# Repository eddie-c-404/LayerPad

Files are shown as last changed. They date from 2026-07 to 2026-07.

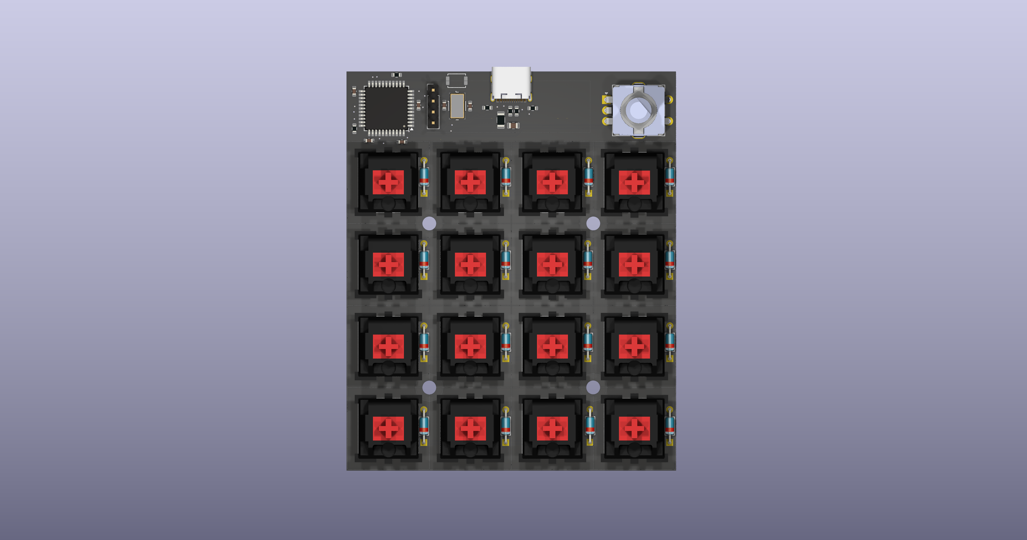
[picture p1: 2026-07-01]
Images/Render_Top_ZO.png

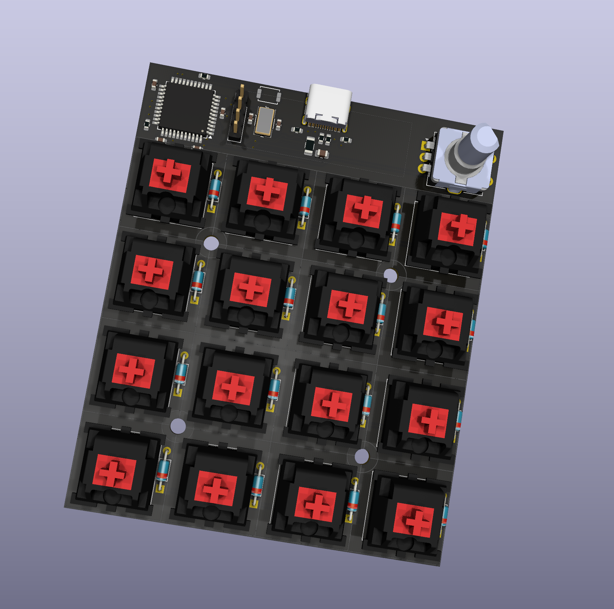
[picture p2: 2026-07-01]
Images/Render_Top2.png

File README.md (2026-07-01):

# LayerPad
Highly customizable macropad for creators.



## Why?
This project was meant to assist me in being more efficient in my day-to-day activities through the use of the shortcut keys and macros which I frequently use. Through the use of programmable keys, several layers, the rotary encoder and an OLED screen, the macropad is able to be programmed for various uses including Visual Studio, Fusion 360, KiCad and Blender. The aim is to have a small but highly customizable productivity aid which can assist anyone in organizing their workspace.
## Features
- 16 programmable mechanical keys

- Rotary encoder with push button

- OLED display

- USB-C connectivity

- Powered by the ATmega32U4

- Compatible with QMK firmware

## 🚧 Build Status 
| Component | Status | 
|---|---|
| PCB Design | 🚧 In Progress | 
| Schematic | 🚧 In Progress | 
| Case Design | 🚧 In Progress | 
| Firmware | ⏳ Planned | 
| Prototype | ⏳ Planned |

## Future Improvements

- RGB underglow

- Multiple rotary encoders

- Wireless (Bluetooth) version

- Aluminum enclosure

- VIA/Vial support

- Low-profile switch version

- Additional OLED animations

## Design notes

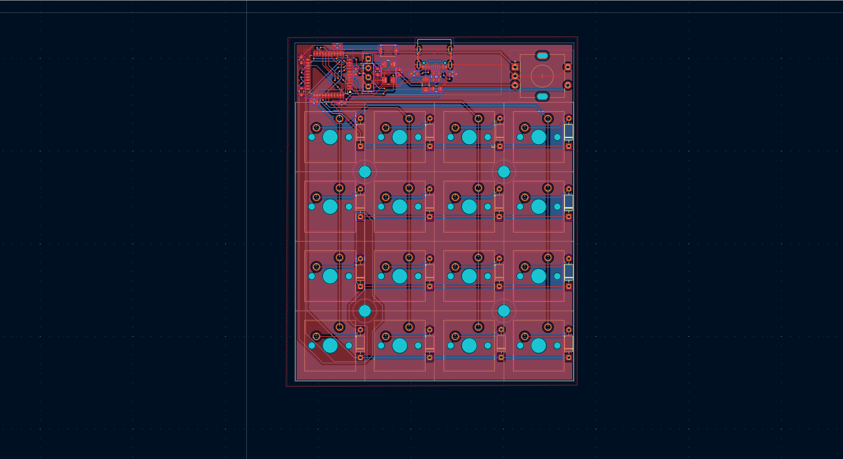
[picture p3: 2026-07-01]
Images/PCB_Top.png

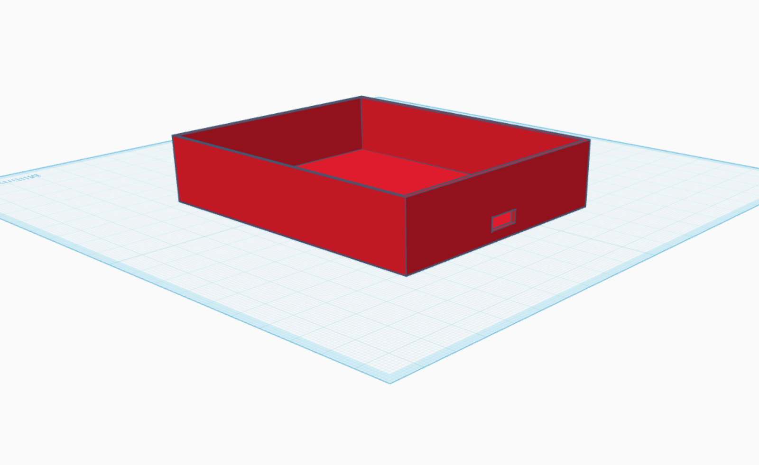
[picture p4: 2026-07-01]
Images/Case_Side.png

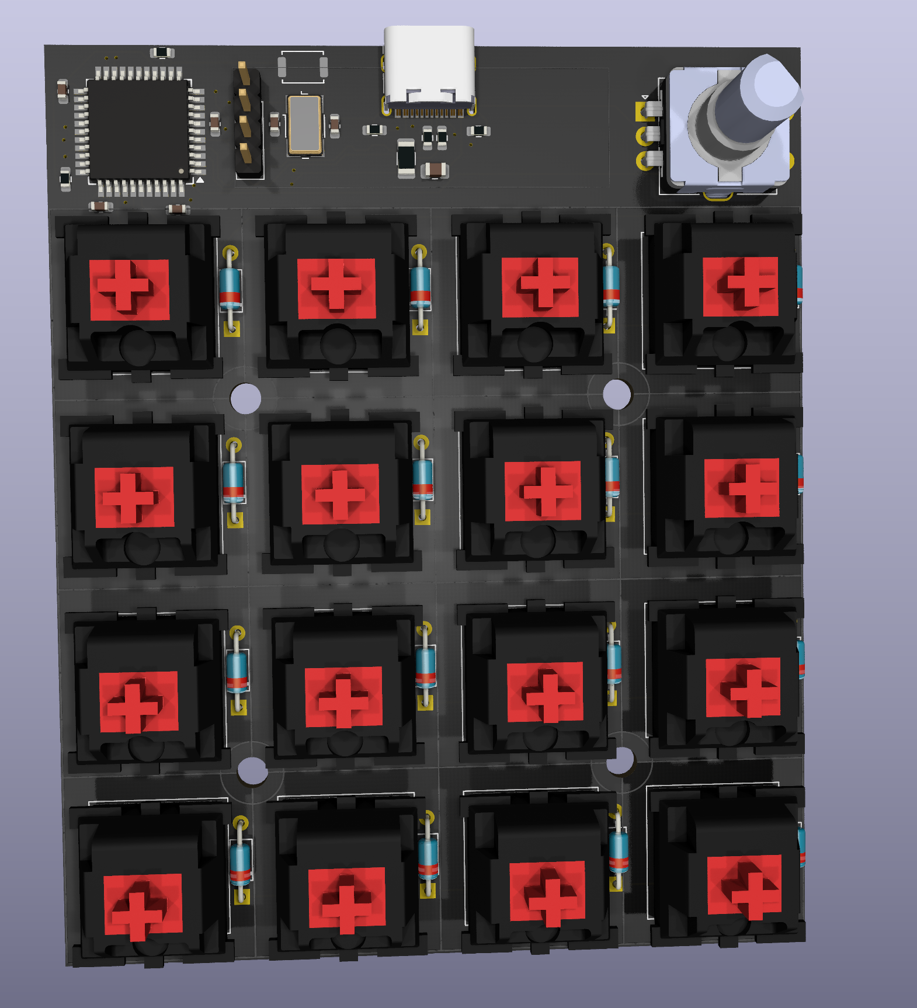
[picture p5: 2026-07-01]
Images/Render_Top.png

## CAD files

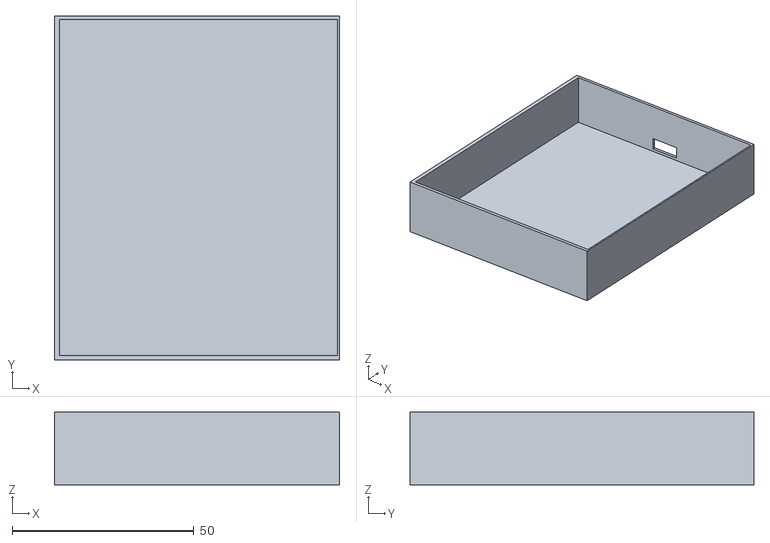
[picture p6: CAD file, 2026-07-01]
3D Files/simpleCase.stl
78.6 x 94.8 x 20.0

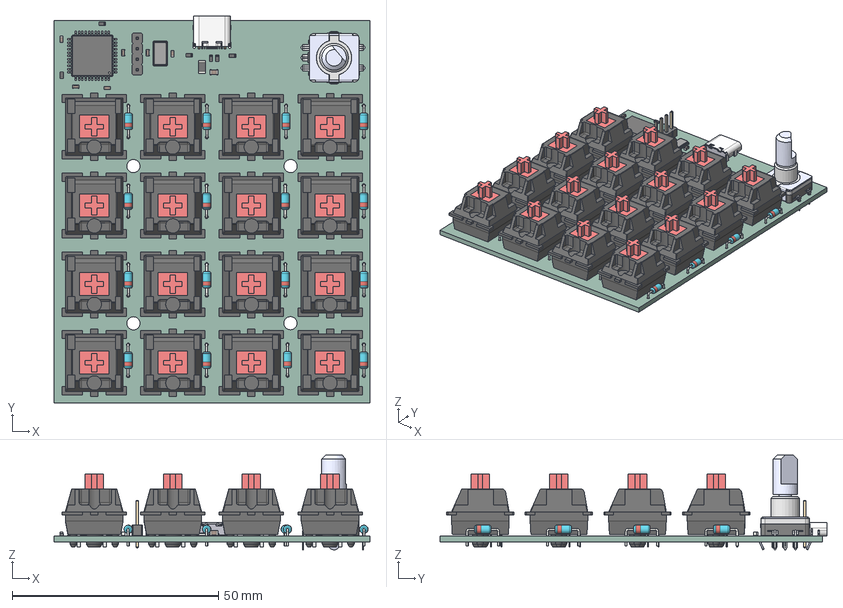
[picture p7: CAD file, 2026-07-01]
KiCad Files/LayerPad-v1.step
76.6 x 93.8 x 23.0 mm
D_DO-35_SOD27_P7.62mm_Horizontal x 16
R_0603_1608Metric x 6
Crystal_SMD_0603-4Pin_6.0x3.5mm
C_0603_1608Metric x 6
PinHeader_1x04_P2.54mm_Vertical
C_0805_2012Metric
tongue
shield
contact_001
contact_002
contact_003
contact_004
contact_court_001
contact_court_002
contact_court_003
contact_court_004
contact_005
contact_006
contact_007
contact_008
contact_court_005
contact_court_006
contact_court_007
contact_court_008
pin_001
pin_002
pin_003
pin_004
pin_005
pin_006
pin_007
pin_008
pin_009
pin_010
pin_011
pin_012
pin_013
pin_014
pin_015
pin_016
Fuse_1206_3216Metric
EC11-Base
EC11-Shaft-F
EC11-Housing-THT
TQFP-44_10x10mm_P0.8mm
LayerPad-v1_PCB

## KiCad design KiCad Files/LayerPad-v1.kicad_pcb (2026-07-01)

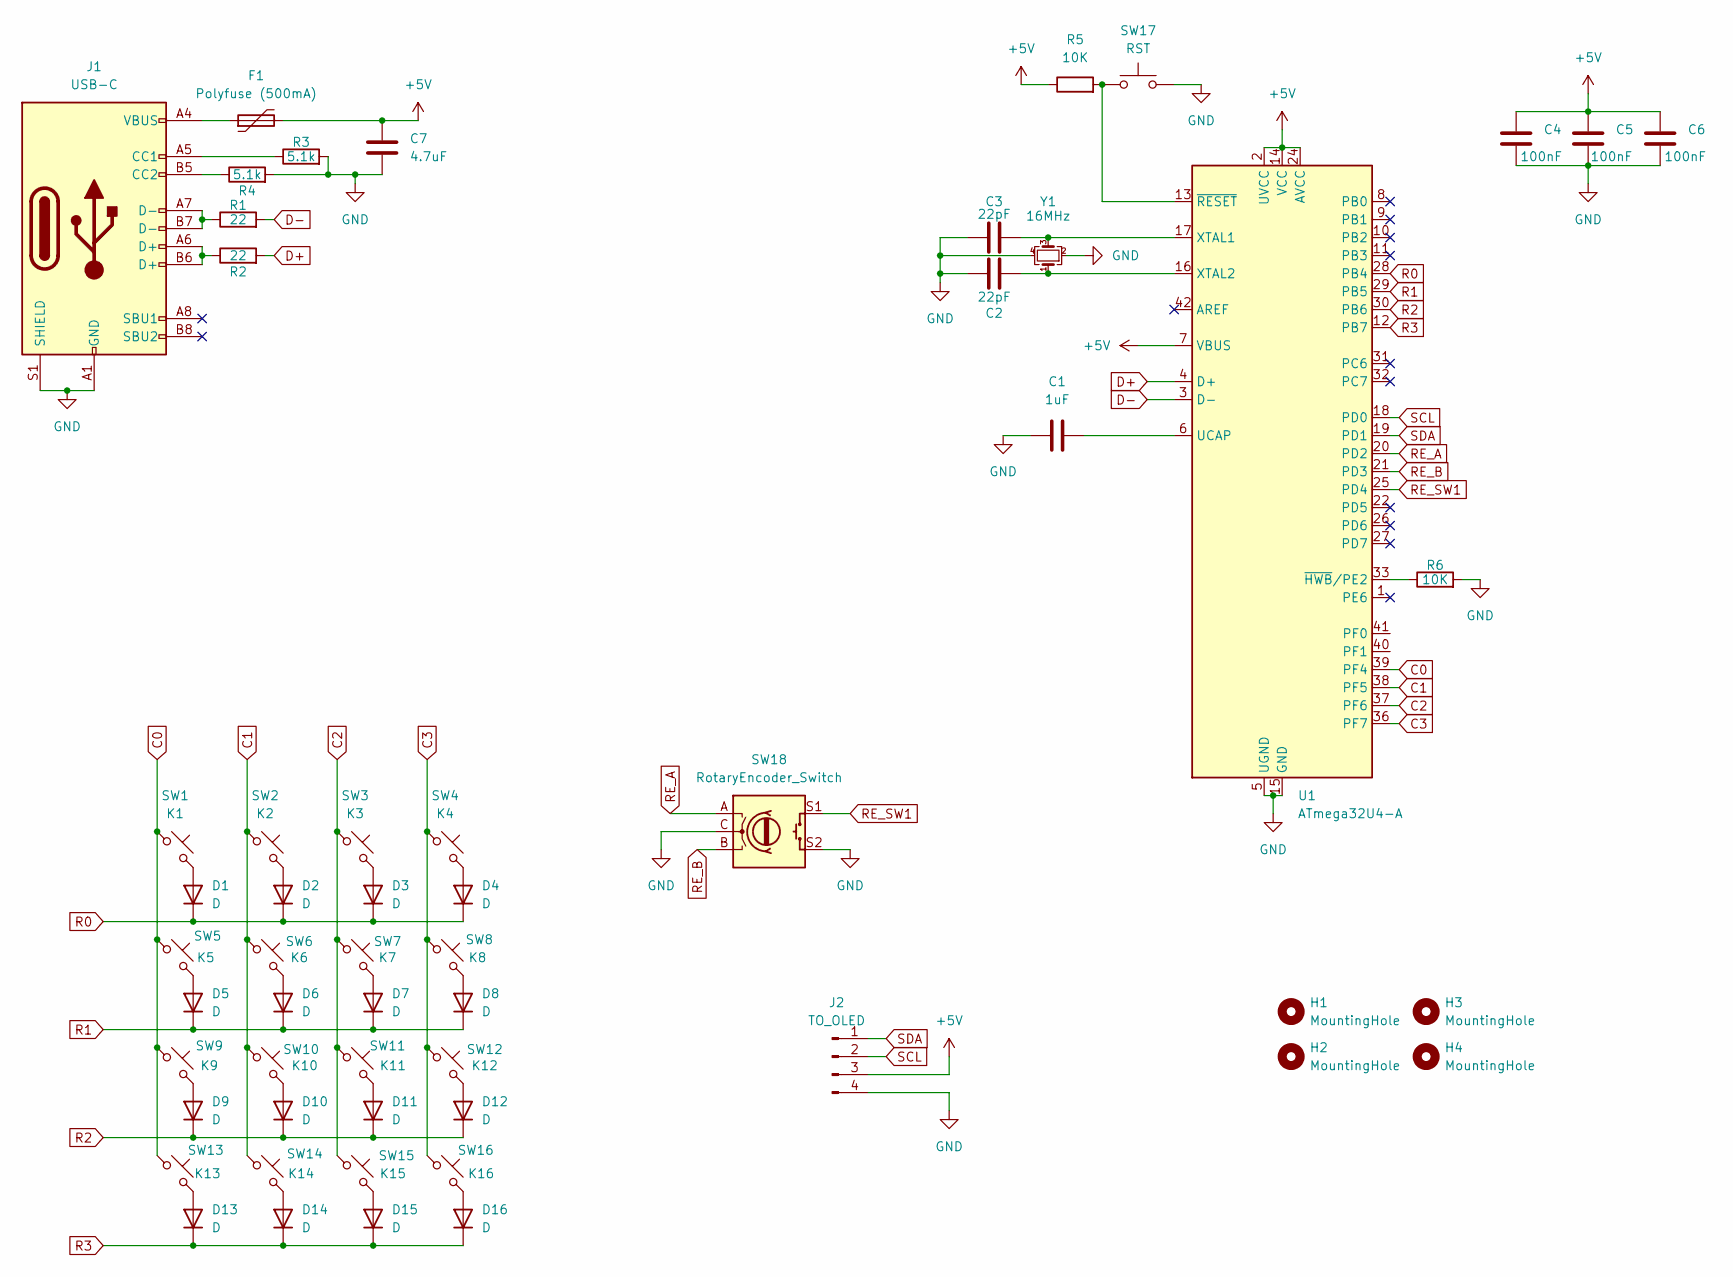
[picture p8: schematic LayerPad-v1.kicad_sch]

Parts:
C1: 1uF; C_0603_1608Metric
C2, C3: 22pF; C_0603_1608Metric
C4, C5, C6: 100nF; C_0603_1608Metric
C7: 4.7uF; C_0805_2012Metric
D1, D2, D3, D4, D5, D6, D7, D8, D9, D10, D11, D12, D13, D14, D15, D16: D; D_DO-35_SOD27_P7.62mm_Horizontal
F1: Polyfuse (500mA); Fuse_1206_3216Metric
H1, H2, H3, H4: MountingHole; MountingHole_3.2mm_M3
J1: USB-C; USB_C_Receptacle_G-Switch_GT-USB-7010ASV
J2: TO_OLED; PinHeader_1x04_P2.54mm_Vertical
R1, R2: 22; R_0603_1608Metric
R3, R4: 5.1k; R_0603_1608Metric
R5, R6: 10K; R_0603_1608Metric
SW1: K1; SW_Cherry_MX_1.00u_PCB
SW2: K2; SW_Cherry_MX_1.00u_PCB
SW3: K3; SW_Cherry_MX_1.00u_PCB
SW4: K4; SW_Cherry_MX_1.00u_PCB
SW5: K5; SW_Cherry_MX_1.00u_PCB
SW6: K6; SW_Cherry_MX_1.00u_PCB
SW7: K7; SW_Cherry_MX_1.00u_PCB
SW8: K8; SW_Cherry_MX_1.00u_PCB
SW9: K9; SW_Cherry_MX_1.00u_PCB
SW10: K10; SW_Cherry_MX_1.00u_PCB
SW11: K11; SW_Cherry_MX_1.00u_PCB
SW12: K12; SW_Cherry_MX_1.00u_PCB
SW13: K13; SW_Cherry_MX_1.00u_PCB
SW14: K14; SW_Cherry_MX_1.00u_PCB
SW15: K15; SW_Cherry_MX_1.00u_PCB
SW16: K16; SW_Cherry_MX_1.00u_PCB
SW17: RST; SW_Push_SPST_NO_Alps_SKRK
SW18: RotaryEncoder_Switch; RotaryEncoder_EC11
U1: ATmega32U4-A; TQFP-44_10x10mm_P0.8mm
Y1: 16MHz; Crystal_SMD_0603-4Pin_6.0x3.5mm

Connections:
+5V: C4.1, C5.1, C6.1, C7.1, F1.2, J2.3, R5.1, U1.2 (UVCC), U1.7 (VBUS), U1.14 (VCC), U1.24 (AVCC), U1.34 (VCC), U1.44 (AVCC)
C0: SW1.1, SW5.1, SW9.1, SW13.1, U1.39 (PF4)
C1: SW2.1, SW6.1, SW10.1, SW14.1, U1.38 (PF5)
C2: SW3.1, SW7.1, SW11.1, SW15.1, U1.37 (PF6)
C3: SW4.1, SW8.1, SW12.1, SW16.1, U1.36 (PF7)
D+: R2.2, U1.4 (D+)
D-: R1.2, U1.3 (D-)
GND: C1.1, C2.1, C3.1, C4.2, C5.2, C6.2, C7.2, J1.A1 (GND), J1.A12 (GND), J1.B1 (GND), J1.B12 (GND), J1.S1 (SHIELD), J2.4, R3.2, R4.2, R6.2, SW17.2, SW18.C, SW18.S2, U1.5 (UGND), U1.15 (GND), U1.23 (GND), U1.35 (GND), U1.43 (GND), Y1.2, Y1.4
unnamed: D1.2 (A), SW1.2
unnamed: D2.2 (A), SW2.2
unnamed: D3.2 (A), SW3.2
unnamed: D4.2 (A), SW4.2
unnamed: D5.2 (A), SW5.2
unnamed: D6.2 (A), SW6.2
unnamed: D7.2 (A), SW7.2
unnamed: D8.2 (A), SW8.2
unnamed: D9.2 (A), SW9.2
unnamed: D10.2 (A), SW10.2
unnamed: D11.2 (A), SW11.2
unnamed: D12.2 (A), SW12.2
unnamed: D13.2 (A), SW13.2
unnamed: D14.2 (A), SW14.2
unnamed: D15.2 (A), SW15.2
unnamed: D16.2 (A), SW16.2
unnamed: F1.1, J1.A4 (VBUS), J1.A9 (VBUS), J1.B4 (VBUS), J1.B9 (VBUS)
unnamed: J1.A5 (CC1), R3.1
unnamed: J1.B5 (CC2), R4.1
unnamed: J1.A6 (D+), J1.B6 (D+), R2.1
unnamed: J1.A7 (D-), J1.B7 (D-), R1.1
unnamed: C1.2, U1.6 (UCAP)
unnamed: C3.2, U1.17 (XTAL1), Y1.3
unnamed: C2.2, U1.16 (XTAL2), Y1.1
unnamed: R6.1, U1.33 (~HWB/PE2)
unnamed: R5.2, SW17.1, U1.13 (~RESET)
R0: D1.1 (K), D2.1 (K), D3.1 (K), D4.1 (K), U1.28 (PB4)
R1: D5.1 (K), D6.1 (K), D7.1 (K), D8.1 (K), U1.29 (PB5)
R2: D9.1 (K), D10.1 (K), D11.1 (K), D12.1 (K), U1.30 (PB6)
R3: D13.1 (K), D14.1 (K), D15.1 (K), D16.1 (K), U1.12 (PB7)
RE_A: SW18.A, U1.20 (PD2)
RE_B: SW18.B, U1.21 (PD3)
RE_SW1: SW18.S1, U1.25 (PD4)
SCL: J2.2, U1.18 (PD0)
SDA: J2.1, U1.19 (PD1)

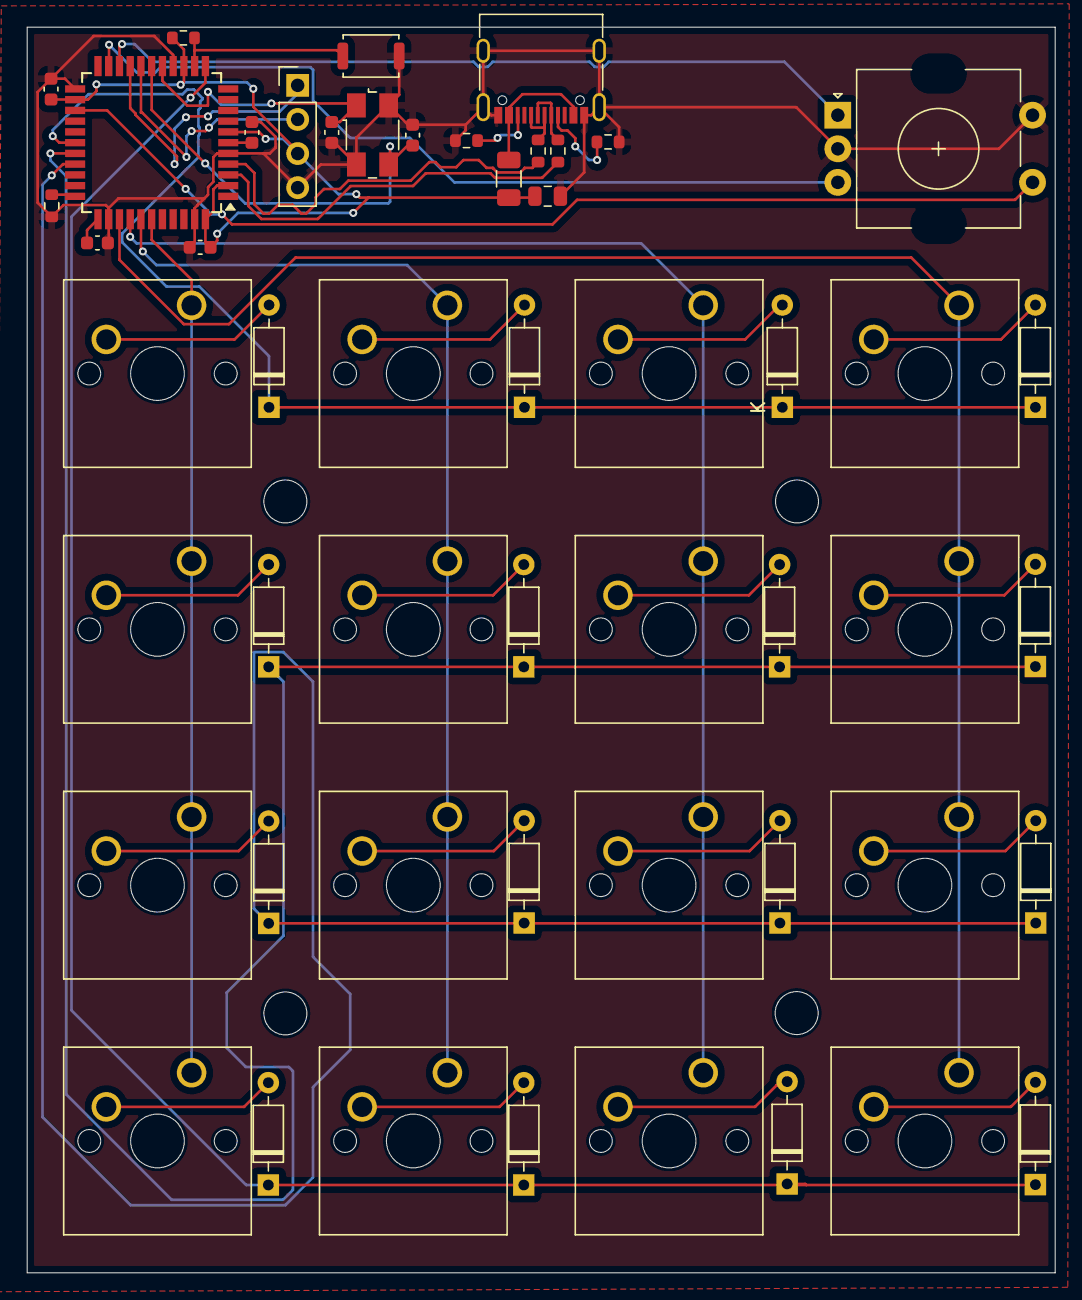
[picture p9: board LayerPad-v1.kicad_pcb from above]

Board: 2 copper layers, 76.6 x 92.8 mm, 56 parts (0 on the bottom side), 43 nets.
